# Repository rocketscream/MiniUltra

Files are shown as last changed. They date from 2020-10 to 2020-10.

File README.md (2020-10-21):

# Mini Ultra
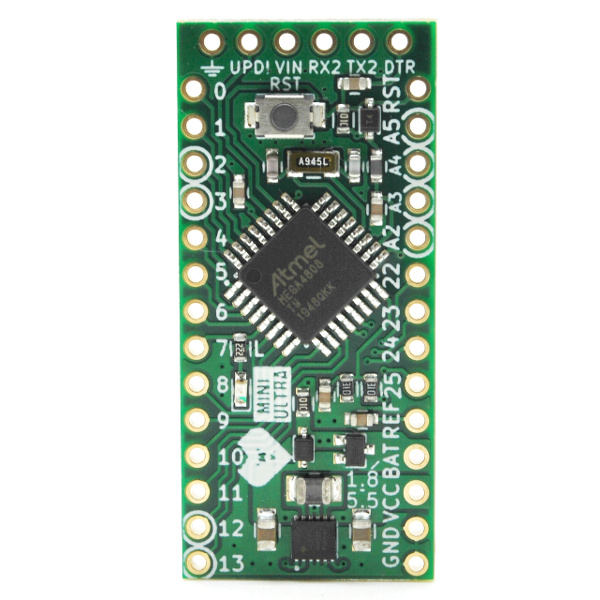
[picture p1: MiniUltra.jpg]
Mini Ultra

An ultra low power Arduino compatible board based on the ATMega4808. The board is able to run from variety type of battery below and above it's 3.3V operating voltage. This allow batteries such as 2xNiMH, 3V CR123A, Li-Ion/Pol, 2 or 3 alkaline and LiFePO4 to be used. Board sleep at 3.7 uA with the on-chip real time counter (RTC) running.

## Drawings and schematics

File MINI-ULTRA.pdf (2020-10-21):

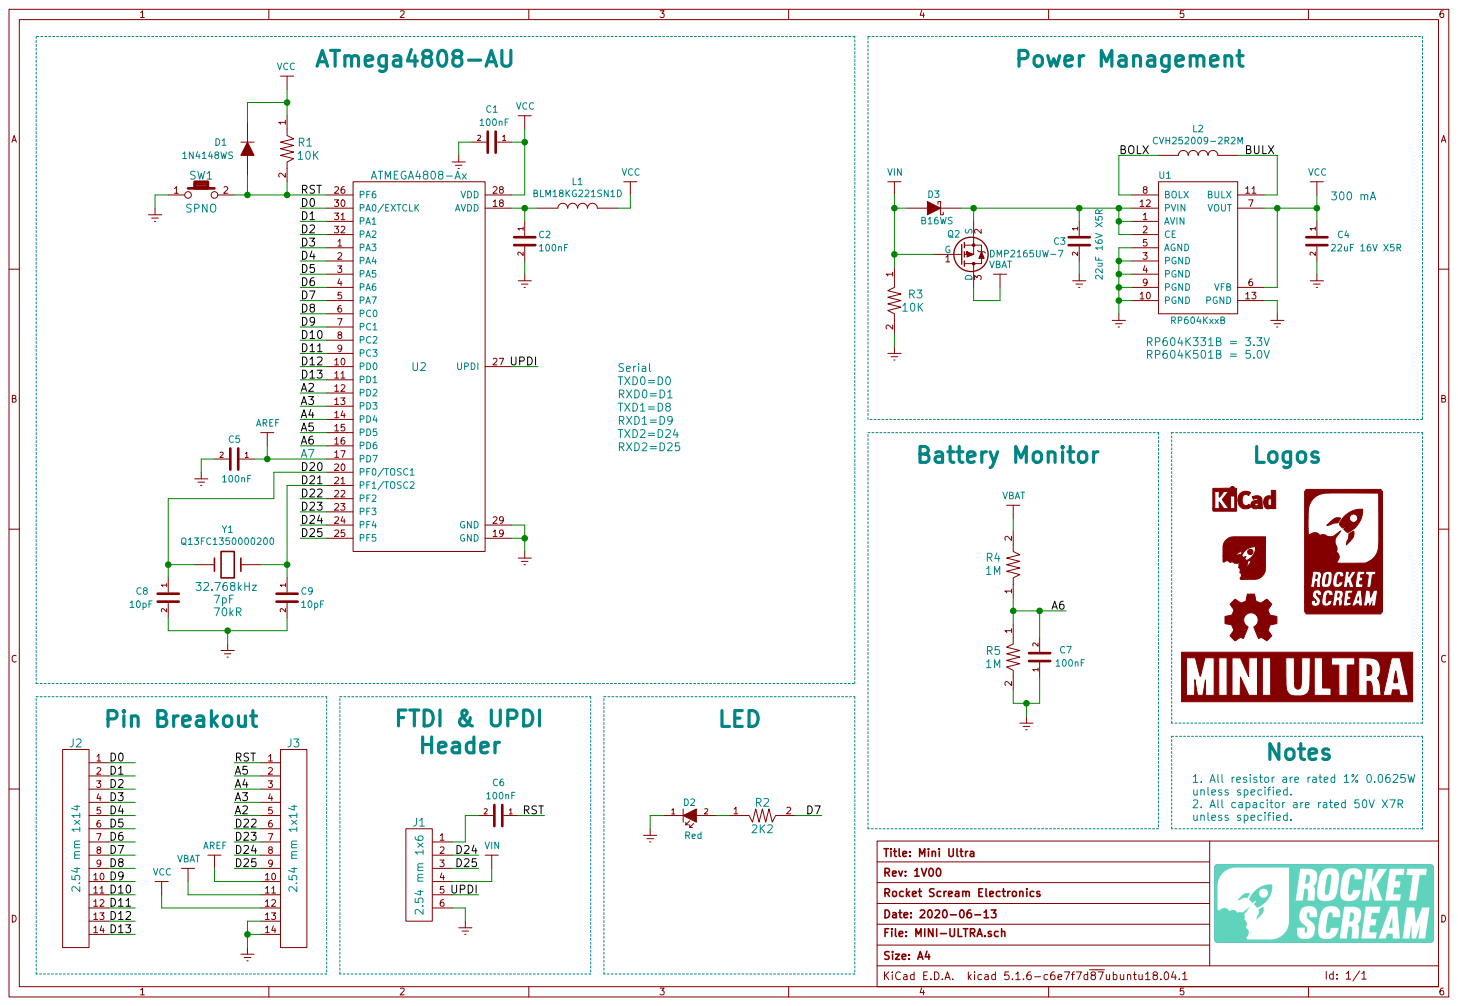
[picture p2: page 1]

1. All resistor are rated 1% 0.0625W unless specified.

2. All capacitor are rated 50V X7R
unless specified.

Id: 1/1 Title: Mini Ultra File: MINI-ULTRA.sch Rocket Scream Electronics
D Date: 2020-06-13 KiCad E.D.A. kicad 5.1.6-c6e7f7d87ubuntu18.04.1 Rev: 1V00 Size: A4

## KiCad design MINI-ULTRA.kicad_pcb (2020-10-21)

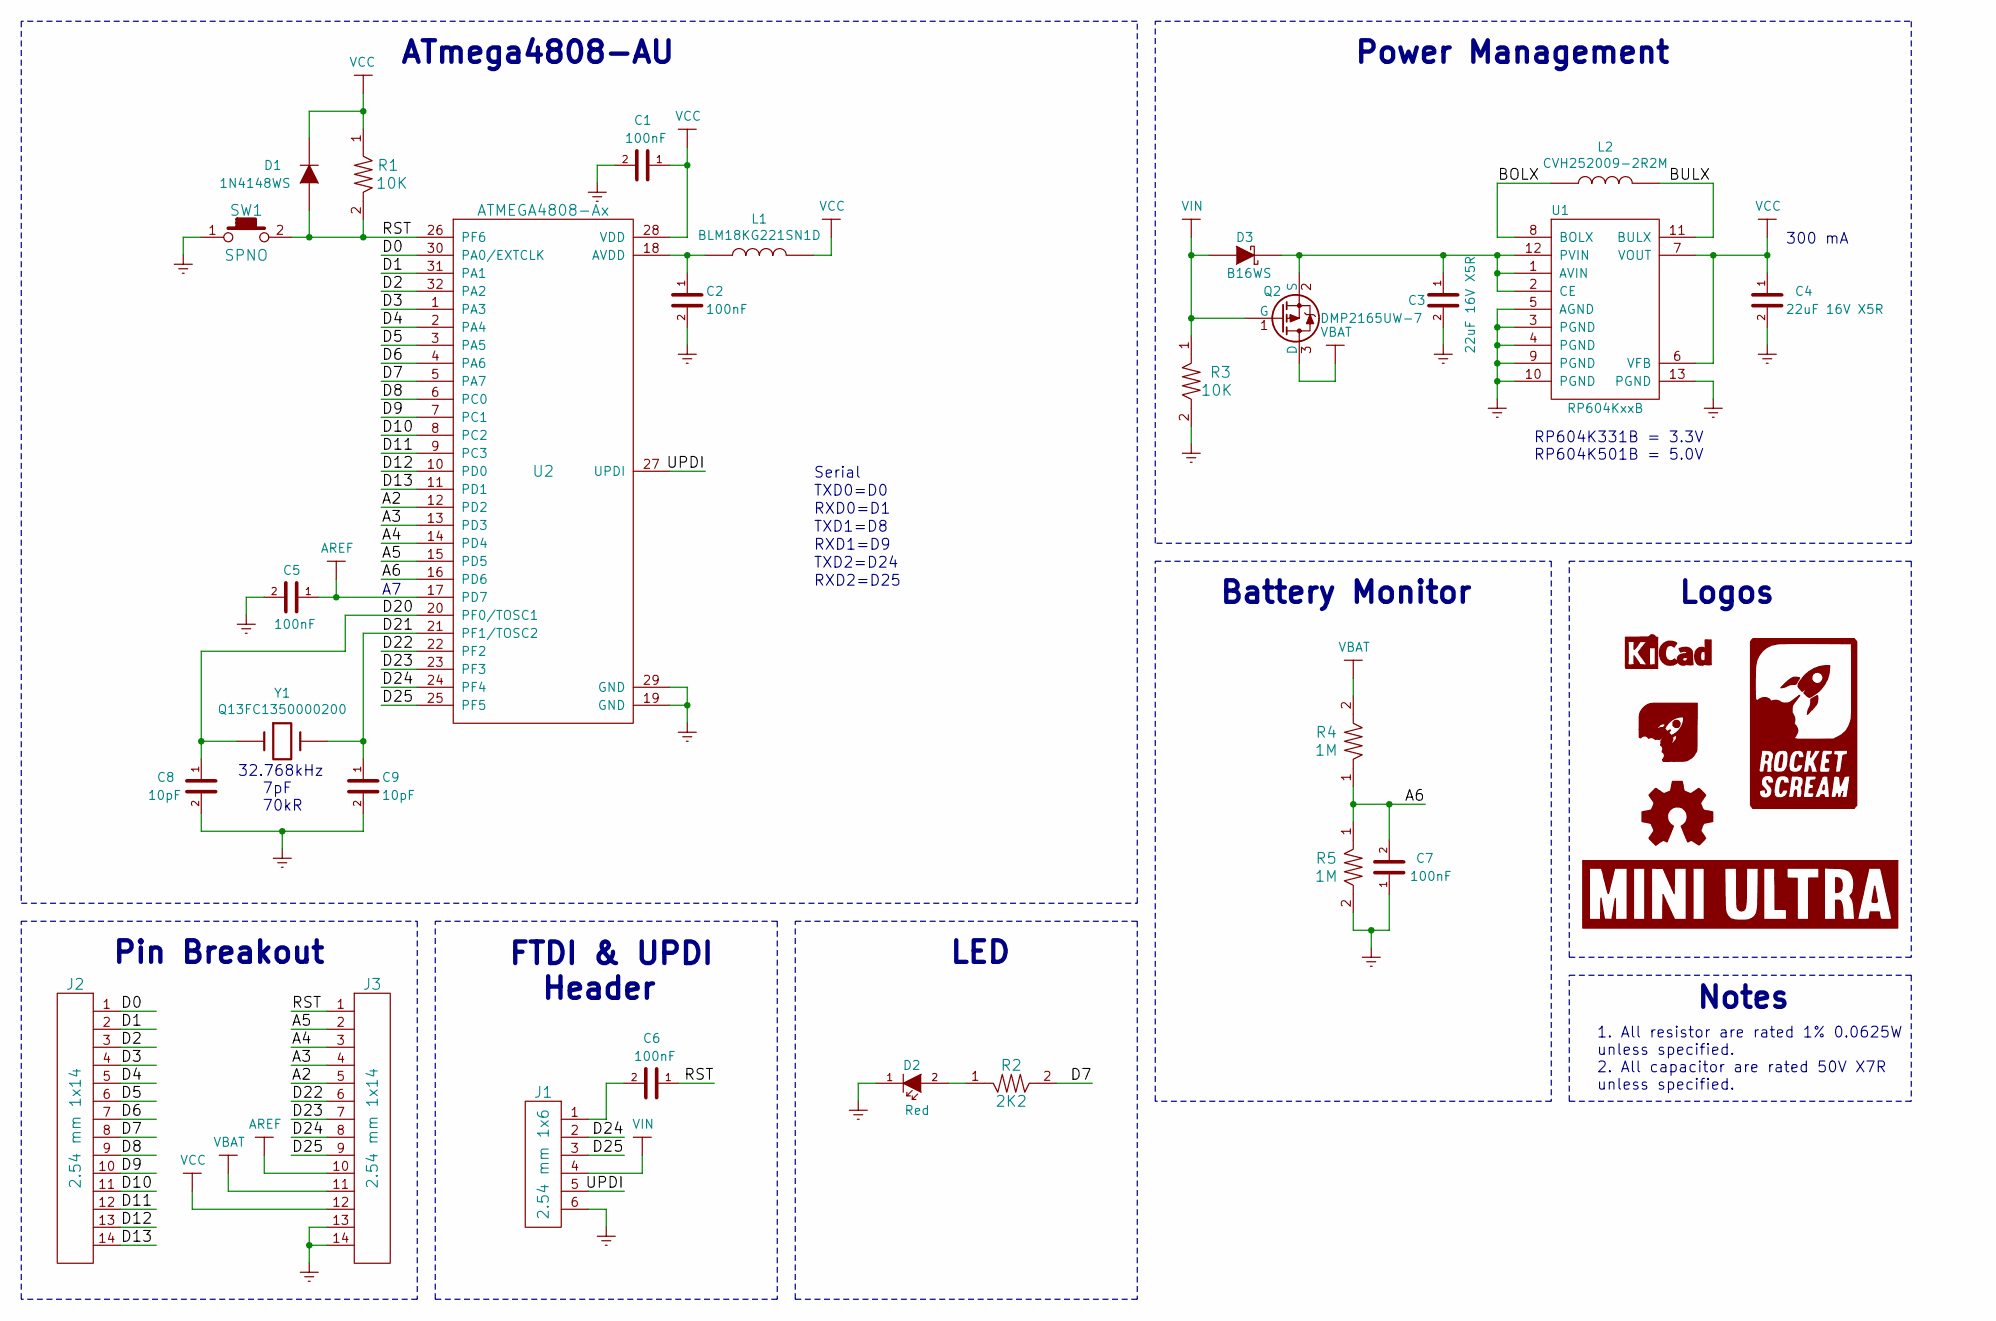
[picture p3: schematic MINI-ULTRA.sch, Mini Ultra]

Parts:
C1, C2, C5, C6, C7: 100nF; C_0603
C3, C4: 22uF 16V X5R; C_0805
C8, C9: 10pF; C_0603
D1: 1N4148WS; SOD-323
D2: Red; LED_0603
D3: B16WS; SOD-323
J1: 2.54 mm 1x6; HDR_1x6_Pitch2.54mm
J2, J3: 2.54 mm 1x14; HDR_1x14_Pitch2.54mm
L1: BLM18KG221SN1D; I_0603
L2: CVH252009-2R2M; I_2520
LOGO1: LOGO-KICAD; LOGO-KICAD_XXXSmall
LOGO2: LOGO-ROCKET-SCREAM-VERTICAL; LOGO-ROCKET-SCREAM_Vertical_XSmall
LOGO3: LOGO-ROCKET-SCREAM-WITHOUT-TEXT; LOGO-ROCKET-SCREAM_Without_Text_XXXXSmall
LOGO4: LOGO-OSHW; LOGO-OSHW_XXSmall
LOGO5: LOGO-MINI-ULTRA; LOGO-MINI-ULTRA_InvertedDualLineSmall
Q2: DMP2165UW-7; SOT-323
R1, R3: 10K; R_0603
R2: 2K2; R_0603
R4, R5: 1M; R_0603
SW1: SPNO; TS-107A
U1: RP604KxxB; DFN-12
U2: ATMEGA4808-Ax; TQFP-32_7x7mm_Pitch0.8mm
Y1: Q13FC1350000200; CRYSTAL-3215-2P

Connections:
/A2: J3.5, U2.12 (PD2)
/A3: J3.4, U2.13 (PD3)
/A4: J3.3, U2.14 (PD4)
/A5: J3.2, U2.15 (PD5)
/A6: C7.2, R4.1, R5.1, U2.16 (PD6)
/BOLX: L2.1, U1.8 (BOLX)
/BULX: L2.2, U1.11 (BULX)
/D0: J2.1, U2.30 (PA0/EXTCLK)
/D1: J2.2, U2.31 (PA1)
/D2: J2.3, U2.32 (PA2)
/D3: J2.4, U2.1 (PA3)
/D4: J2.5, U2.2 (PA4)
/D5: J2.6, U2.3 (PA5)
/D6: J2.7, U2.4 (PA6)
/D7: J2.8, R2.2, U2.5 (PA7)
/D8: J2.9, U2.6 (PC0)
/D9: J2.10, U2.7 (PC1)
/D10: J2.11, U2.8 (PC2)
/D11: J2.12, U2.9 (PC3)
/D12: J2.13, U2.10 (PD0)
/D13: J2.14, U2.11 (PD1)
/D20: C8.1, U2.20 (PF0/TOSC1), Y1.1
/D21: C9.1, U2.21 (PF1/TOSC2), Y1.2
/D22: J3.6, U2.22 (PF2)
/D23: J3.7, U2.23 (PF3)
/D24: J1.2, J3.8, U2.24 (PF4)
/D25: J1.3, J3.9, U2.25 (PF5)
/RST: C6.1, D1.2 (A), J3.1, R1.2, SW1.2, U2.26 (PF6)
/UPDI: J1.5, U2.27 (UPDI)
AREF: C5.1, J3.10, U2.17 (PD7)
GND: C1.2, C2.2, C3.2, C4.2, C5.2, C7.1, C8.2, C9.2, D2.1 (K), J1.6, J3.13, J3.14, R3.2, R5.2, SW1.1, U1.3 (PGND), U1.4 (PGND), U1.5 (AGND), U1.9 (PGND), U1.10 (PGND), U1.13 (PGND), U2.19 (GND), U2.29 (GND)
unnamed: C2.1, L1.1, U2.18 (AVDD)
unnamed: C3.1, D3.1 (K), Q2.2 (S), U1.1 (AVIN), U1.2 (CE), U1.12 (PVIN)
unnamed: C6.2, J1.1
unnamed: D2.2 (A), R2.1
VBAT: J3.11, Q2.3 (D), R4.2
VCC: C1.1, C4.1, D1.1 (K), J3.12, L1.2, R1.1, U1.6 (VFB), U1.7 (VOUT), U2.28 (VDD)
VIN: D3.2 (A), J1.4, Q2.1 (G), R3.1

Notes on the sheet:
Power Management
ATmega4808-AU
LED
1. All resistor are rated 1% 0.0625W unless specified. 2. All capacitor are rated 50V X7R unless specified.
Notes
Logos
FTDI & UPDI Header
Pin Breakout
RP604K331B = 3.3V RP604K501B = 5.0V
Battery Monitor
TXD2=D24
RXD2=D25
32.768kHz 7pF 70kR
TXD1=D8
RXD1=D9
TXD0=D0
RXD0=D1
Serial
300 mA

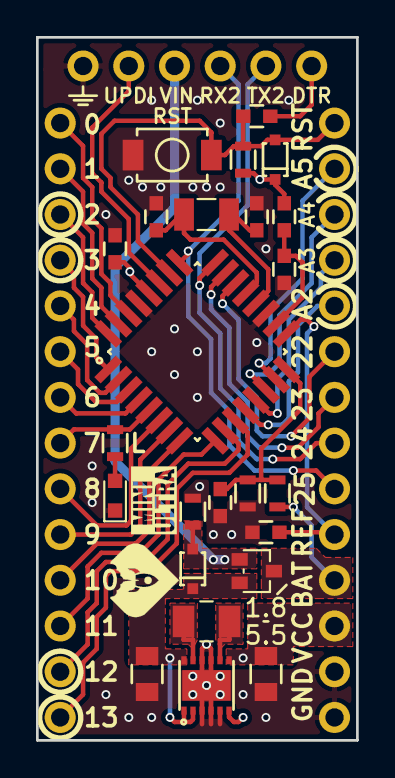
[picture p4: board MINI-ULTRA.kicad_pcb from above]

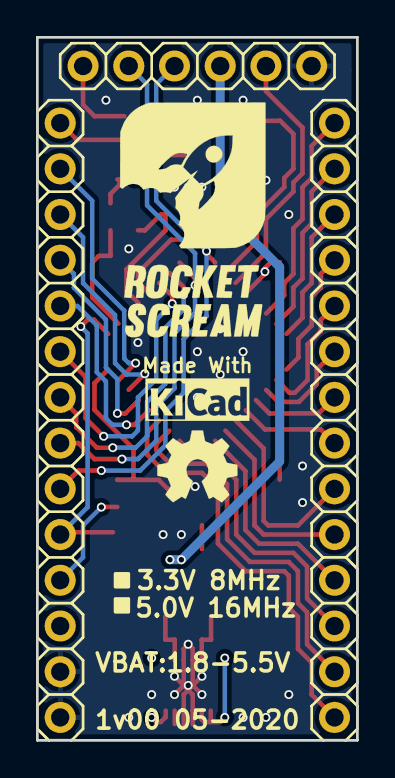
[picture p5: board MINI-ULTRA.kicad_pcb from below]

Board: 4 copper layers, 17.8 x 39.1 mm, 32 parts (6 on the bottom side), 38 nets.
